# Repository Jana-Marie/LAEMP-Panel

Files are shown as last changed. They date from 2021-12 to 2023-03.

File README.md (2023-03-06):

# LAEMP-Panel

LAEMP-Panel is a Zigbee controllable (e.g. philips hue) RGBY + W spot, which can be soldered at home and is easy to assemble. The extra yellow channel gives a much wider dynamic. This is archived by alternating CW/WW/A (Cold-, Warm-White, Amber) and RGB LEDs. LAEMP-Panel can be mounted on mini-tripods and is powered via 5V USB Type-C. A ZigBee bridge (e.g. Philips Hue) is needed for control.

<table>
  <tbody>
    <tr>
      <td>
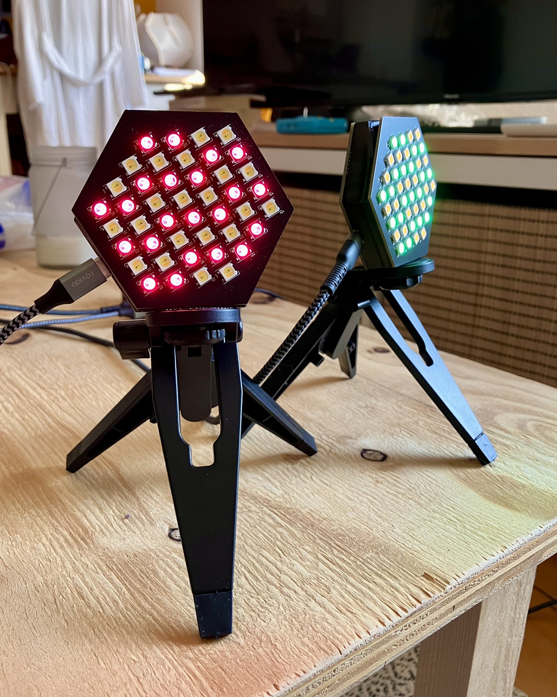
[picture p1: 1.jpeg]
        
      </td>
      <td>
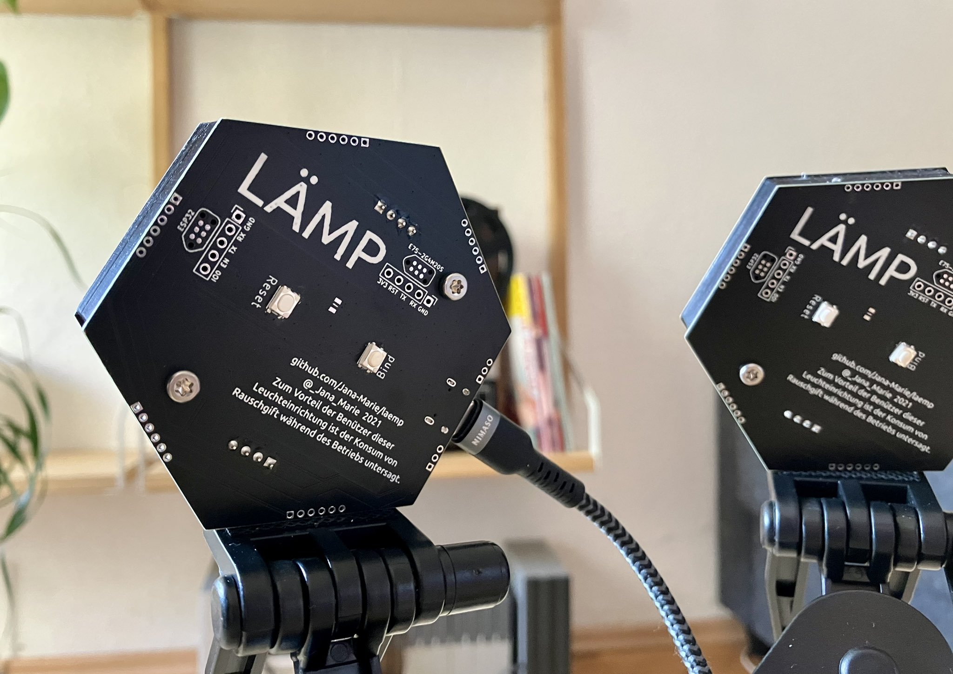
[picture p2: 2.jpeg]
        
      </td>
    </tr>
  </tbody>
</table>

### Sister project

LAEMP-Panel is a sister project to [LAEMP-Prism](https://github.com/Jana-Marie/LAEMP-Prism)

## Firmware

There are two firmwares to be flashed, one for the ESP32 and one for the E75-2G4M20S.

### ESP32

This is a simple Arduino project and can be flashed via Arduino (initially built on Arduino 1.8.19).

### E75

Please refer to the awesome works of [PeeVeeOne](https://peeveeone.com/zll-tldr/) to flash `Light_ColorLight_JN5168_RGB` onto the E75-2G4M20S module.

## Todo

 - [ ] Profile CRI
   - [ ] Increase CRI by selectively adding colors to WW/CW (i.e. green)
 - [ ] Update Baseboard to v2

## License

Copyright Jana Marie Hemsing 2023.
This source describes Open Hardware and is licensed under the CERN-
OHL-S v2.

You may redistribute and modify this source and make products using it
under the terms of the CERN-OHL-S v2
([LICENSE](/LICENSE)).

This source is distributed WITHOUT ANY EXPRESS OR IMPLIED
WARRANTY, INCLUDING OF MERCHANTABILITY, SATISFACTORY
QUALITY AND FITNESS FOR A PARTICULAR PURPOSE. Please see
the CERN-OHL-S v2 for applicable conditions.

Source location: https://github.com/Jana-Marie/LAEMP-Panel/
As per CERN-OHL-S v2 section 4, should You produce hardware based
on this source, You must where practicable maintain the Source Location
visible on the external case of LAEMP-Panel or other products you make using
this source

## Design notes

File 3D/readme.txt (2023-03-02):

You might need to change the height of the 3D printed part by a few mm depending on your printer. 14mm worked out well for me on an Anycubic Photon UV resin printer.

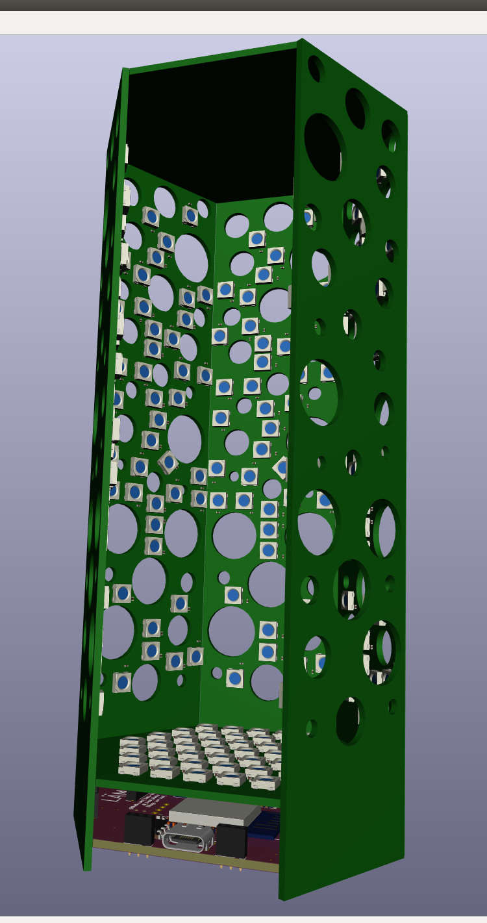
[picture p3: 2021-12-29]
design/img/full_open.png

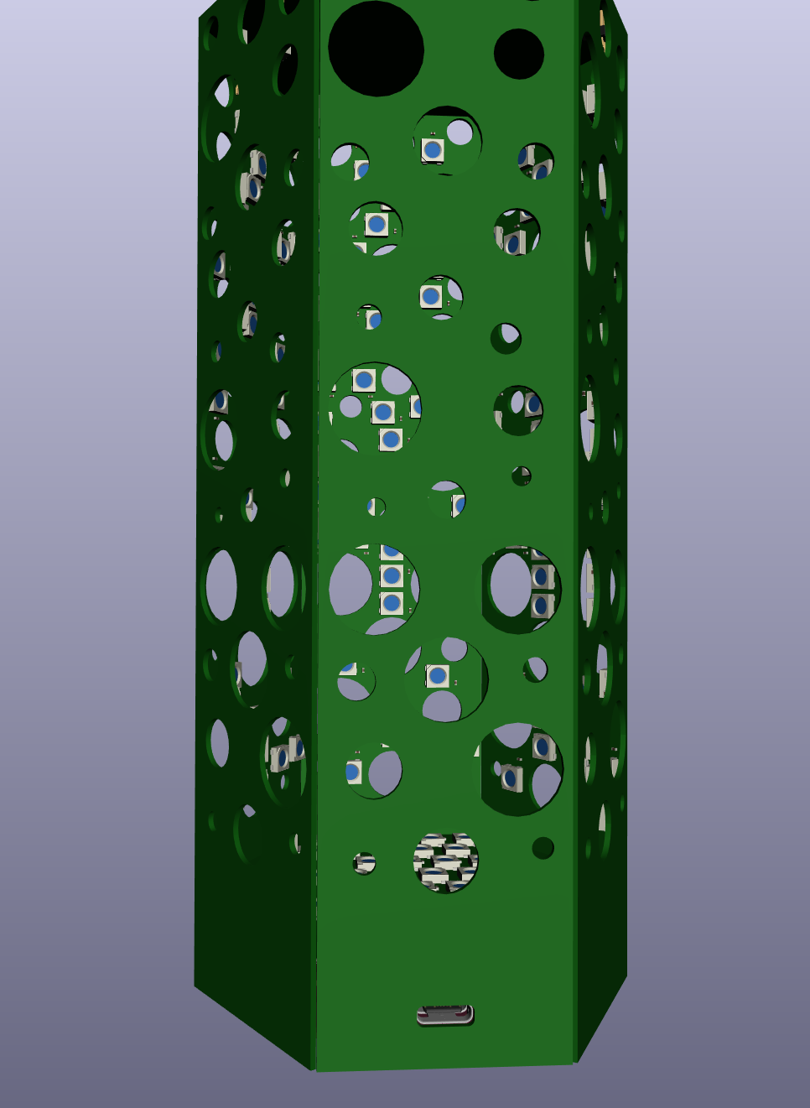
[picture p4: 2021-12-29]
design/img/usb.png

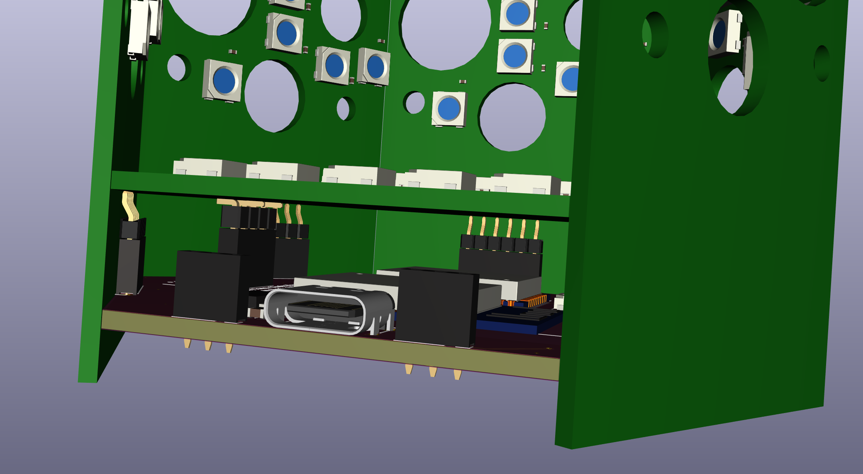
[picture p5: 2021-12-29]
design/img/mainboard.png

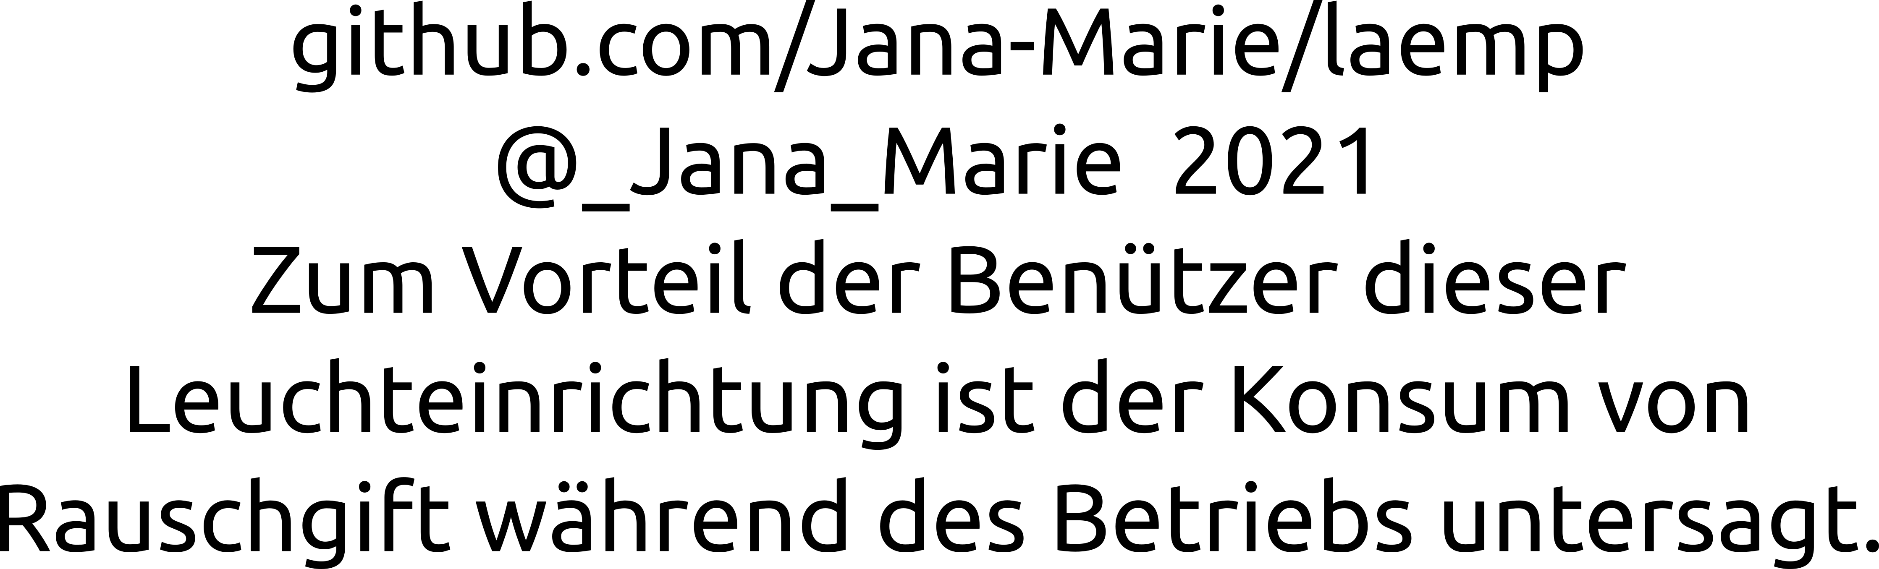
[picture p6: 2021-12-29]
design/bottom_text.png

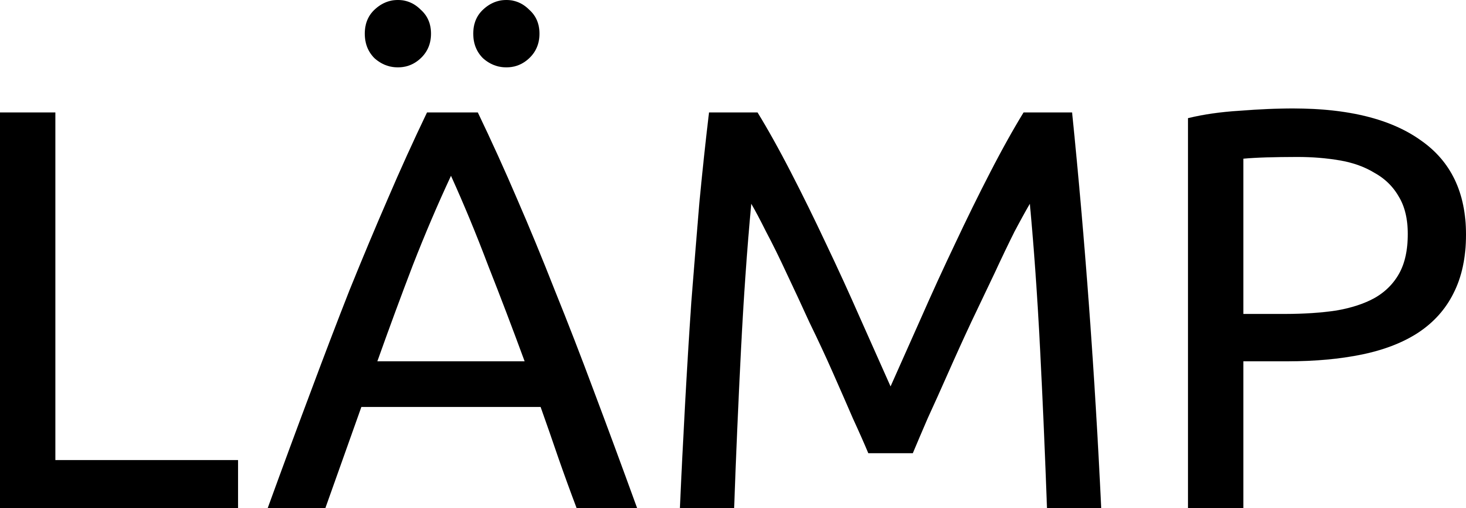
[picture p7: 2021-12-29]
design/laemp.png

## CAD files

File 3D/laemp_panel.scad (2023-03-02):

$fn=100;

color([0, 49/255, 83/255])laemp_panel_inner3D(14, false);

module laemp_panel_inner3D(h=10, thread=false){
    union(){
        // outer hexagon
        difference(){
            rotate([0,0,90])hexagon(40,h);
            translate([0,0,-0.5])rotate([0,0,90])hexagon(36,h+1);
            // usb cutout
            translate([-33,0,3.2/2-0.5])minkowski(){
                d=2;
                cube([5,9.5-d,3.2+1-d],center=true);
                rotate([0,90,0])cylinder(d=d,h=0.1);
            }
            // 1/4" thread
            if(thread==true){
                rotate([90,0,-30])translate([0,h/2,30])thread(6.35,5.35,1.27,6,10);
            } else {
                reduce=1.6;
                rotate([90,0,-30])translate([0,h/2,30])cylinder(d=6.35-reduce, h=6);
            }
        }
        // screwholes
        translate([-17,20,0])mounting_holes(2.5,h,2);
        translate([17,-20,0])mounting_holes(2.5,h,2);
        // bridges
        translate([-17,20,h/2]){
            rotate([0,0,90])translate([3+2,0,0])cube([6,2,h],center=true);
            rotate([0,0,170])translate([5+2,0,0])cube([10,2,h],center=true);
        }
        translate([17,-20,h/2]){
            rotate([0,0,-90])translate([3+2,0,0])cube([6,2,h],center=true);
            rotate([0,0,-10])translate([5+2,0,0])cube([10,2,h],center=true);
        }
    }
}

module thread(do=10,di=9,s=1.9,h=10,res=5){
    ssize=360/res;
    for(i=[1:res:360/s*h]){
        rotate([0,0,i])translate([(do-di)/2,0,s*i/360-0.01])cylinder(h=s/ssize+0.02,d=di);
    }
}

module mounting_holes(sDia=3,h=1,wall=2){
    difference(){
        cylinder(d=wall*2+sDia,h=h);
        translate([0,0,-0.5])cylinder(d=sDia,h=h+1);
    }
}

module hexagon(x = 10, h = 1){
    cylinder(d=x*2, h=h, $fn=6);
}

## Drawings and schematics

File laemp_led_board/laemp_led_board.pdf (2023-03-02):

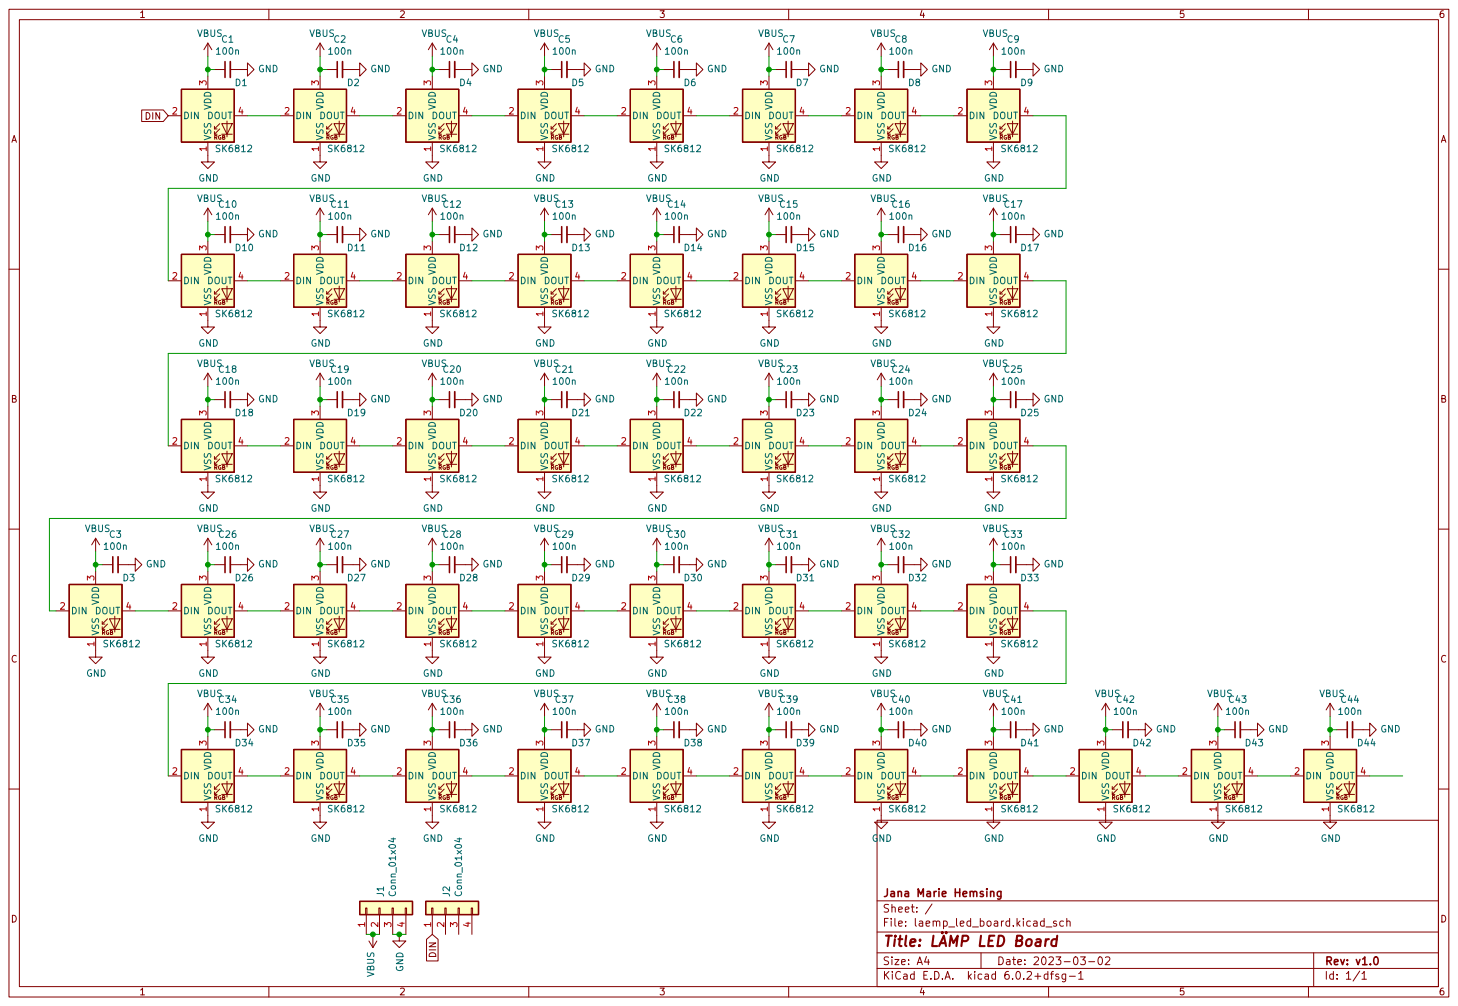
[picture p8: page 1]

3 DOUT 4D35 SK6812 GND GND GND GND VSS RGB 1 DIN 2 VDD

3 DOUT 4D6 SK6812 VBUS VSS RGB 1 DIN 2 VDD

3 DOUT 4D8 SK6812 GNDVSS RGB 1 DIN 2 VDD

3 DOUT 4D11 SK6812 VSS RGB 1 DIN 2 VDD

3 DOUT 4D27 SK6812 VSS RGB 1 DIN 2 VDD

3 DOUT 4D19 SK6812 GND VSS RGB 1 DIN 2 VDD

3 DOUT 4D14 SK6812 GND VSS RGB 1 DIN 2 VDD

3 DOUT 4D15 SK6812 VSS RGB 1 DIN 2 VDD

3 DOUT 4D13 SK6812 VSS RGB 1 DIN 2 VDD

3 DOUT 4D32 SK6812 VBUS GND VSS RGB 1 DIN 2 VDD

3 DOUT 4D25 SK6812 VBUS GND GND

3 DOUT 4D28 SK6812 VSS RGB 1 DIN 2 VDD

File: laemp_led_board.kicad_sch Sheet: / Jana Marie Hemsing

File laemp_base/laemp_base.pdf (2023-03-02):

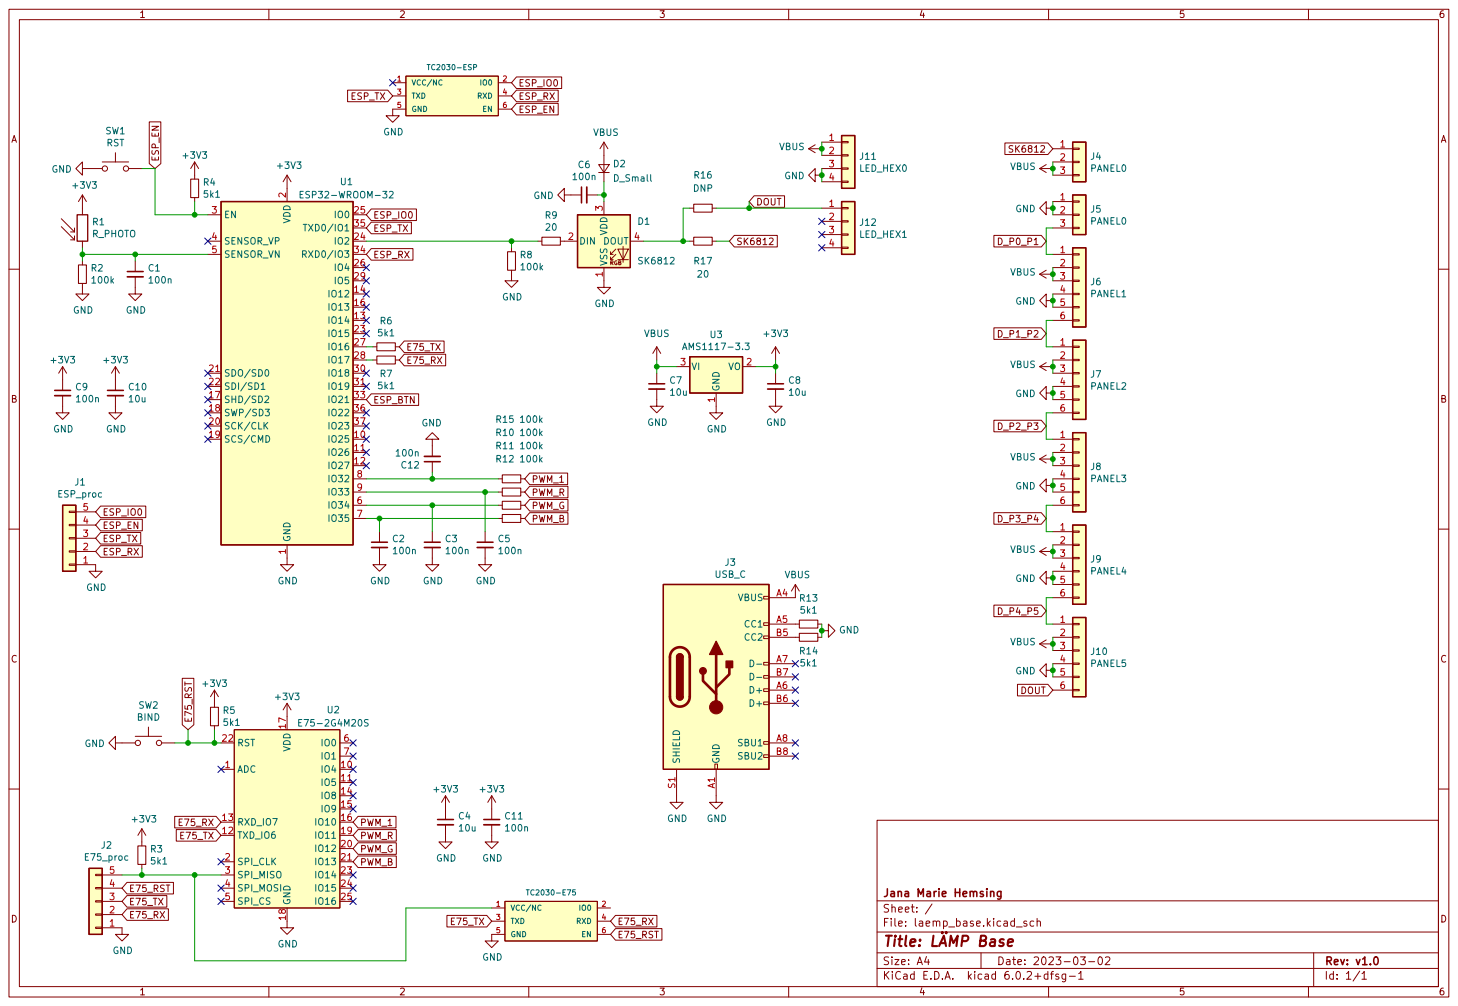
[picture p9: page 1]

File: laemp_base.kicad_sch Sheet: / Jana Marie Hemsing

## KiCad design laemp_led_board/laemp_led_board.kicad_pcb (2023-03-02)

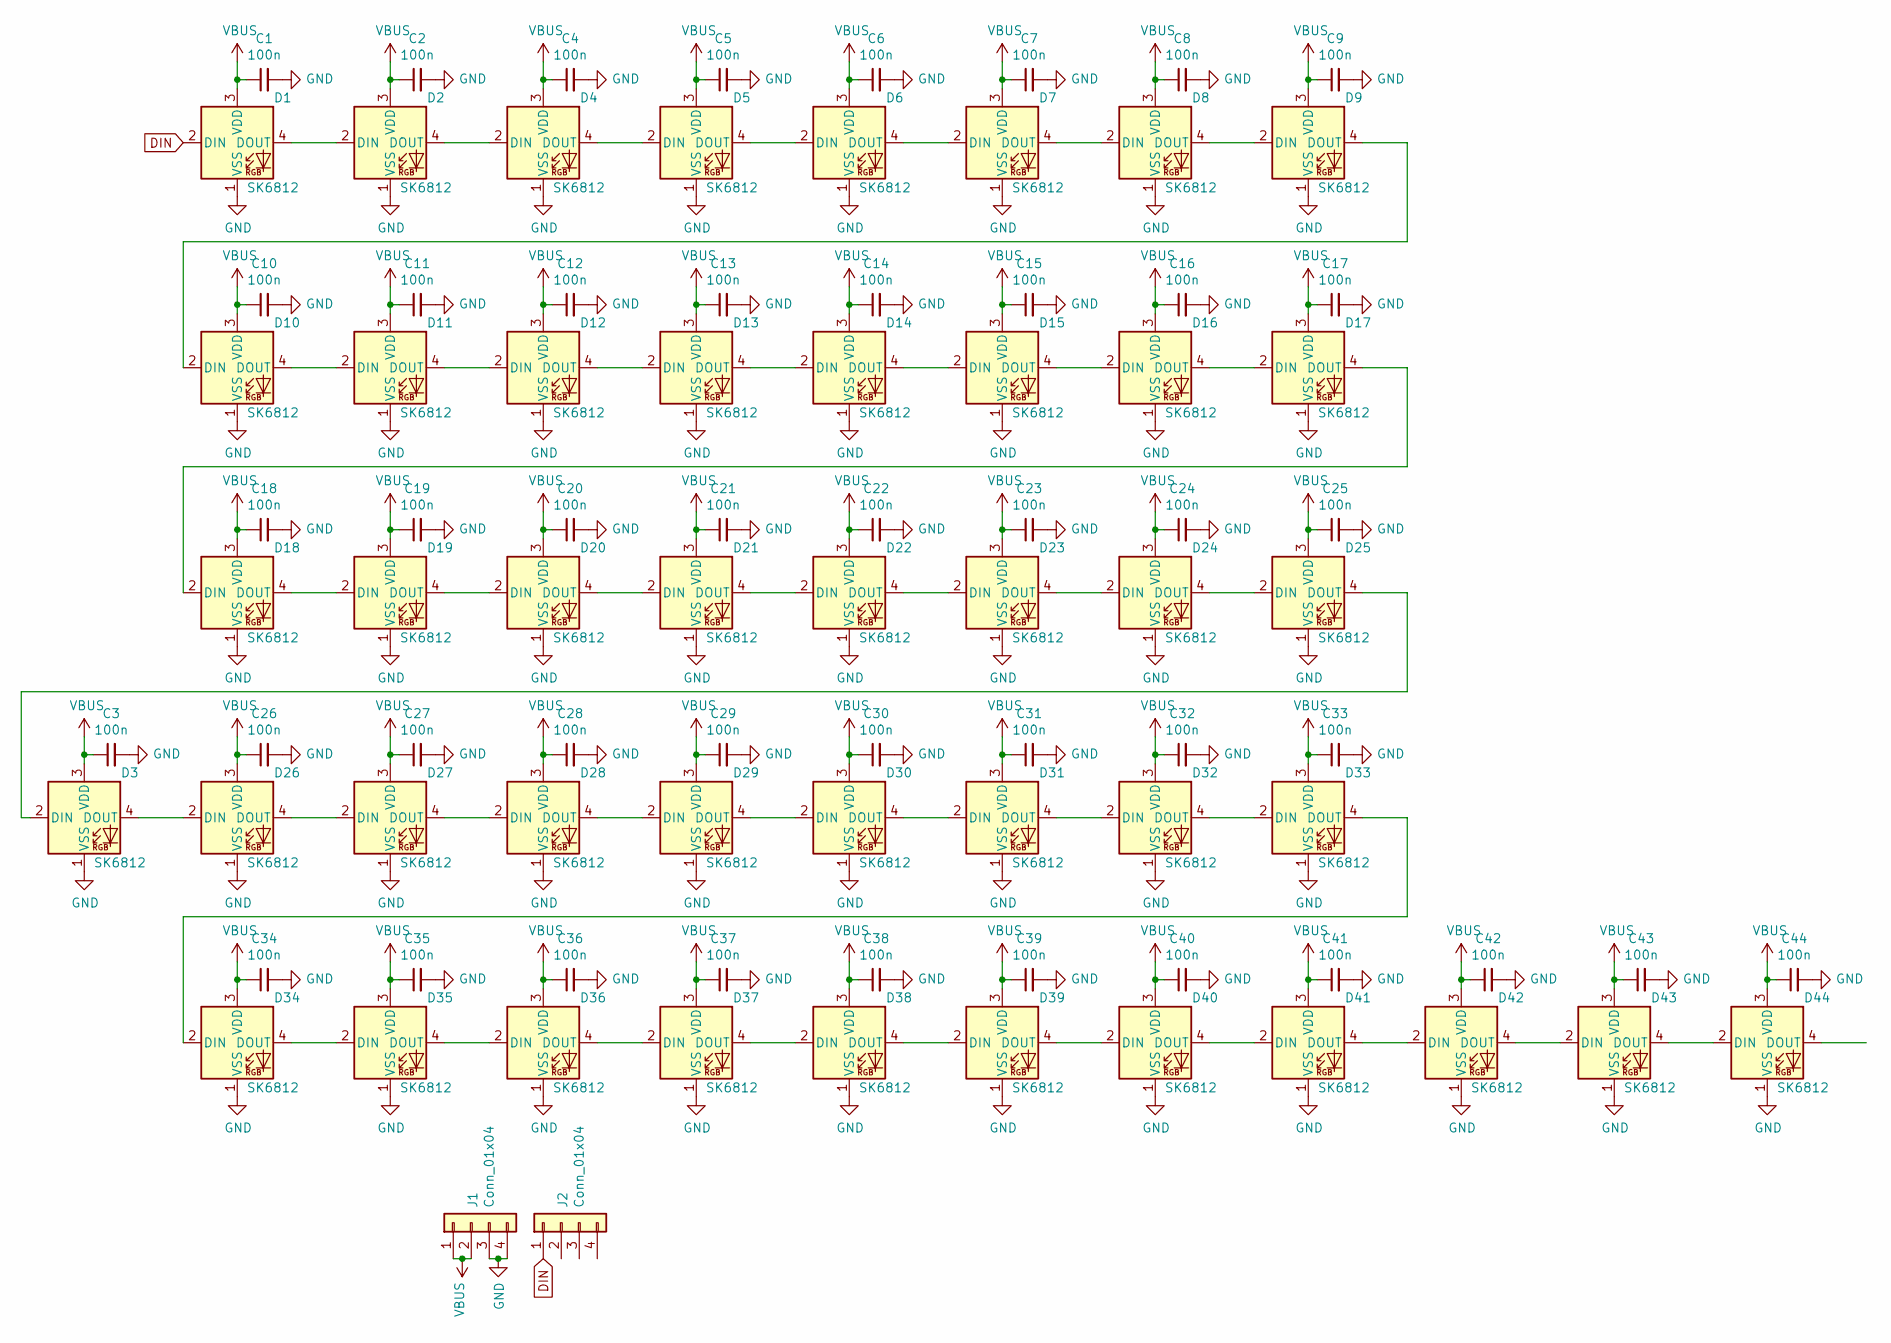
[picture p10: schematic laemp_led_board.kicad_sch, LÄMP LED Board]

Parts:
C1, C2, C3, C4, C5, C6, C7, C8, C9, C10, C11, C12, C13, C14, C15, C16, C17, C18, C19, C20, C21, C22, C23, C24, C25, C26, C27, C28, C29, C30, C31, C32, C33, C34, C35, C36, C37, C38, C39, C40, C41, C42, C43, C44: 100n; C_0402
D1, D2, D3, D4, D5, D6, D7, D8, D9, D10, D11, D12, D13, D14, D15, D16, D17, D18, D19, D20, D21, D22, D23, D24, D25, D26, D27, D28, D29, D30, D31, D32, D33, D34, D35, D36, D37, D38, D39, D40, D41, D42, D43, D44: SK6812; LED_SK6812_PLCC4_5.0x5.0mm_P3.2mm
J1, J2: Conn_01x04; PinHeader_1x04_P2.54mm_Vertical_SMD_Pin1Left

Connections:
DIN: D1.2 (DIN), J2.1
GND: C1.2, C2.2, C3.2, C4.2, C5.2, C6.2, C7.2, C8.2, C9.2, C10.2, C11.2, C12.2, C13.2, C14.2, C15.2, C16.2, C17.2, C18.2, C19.2, C20.2, C21.2, C22.2, C23.2, C24.2, C25.2, C26.2, C27.2, C28.2, C29.2, C30.2, C31.2, C32.2, C33.2, C34.2, C35.2, C36.2, C37.2, C38.2, C39.2, C40.2, C41.2, C42.2, C43.2, C44.2, D1.1 (VSS), D2.1 (VSS), D3.1 (VSS), D4.1 (VSS), D5.1 (VSS), D6.1 (VSS), D7.1 (VSS), D8.1 (VSS), D9.1 (VSS), D10.1 (VSS), D11.1 (VSS), D12.1 (VSS), D13.1 (VSS), D14.1 (VSS), D15.1 (VSS), D16.1 (VSS), D17.1 (VSS), D18.1 (VSS), D19.1 (VSS), D20.1 (VSS), D21.1 (VSS), D22.1 (VSS), D23.1 (VSS), D24.1 (VSS), D25.1 (VSS), D26.1 (VSS), D27.1 (VSS), D28.1 (VSS), D29.1 (VSS), D30.1 (VSS), D31.1 (VSS), D32.1 (VSS), D33.1 (VSS), D34.1 (VSS), D35.1 (VSS), D36.1 (VSS), D37.1 (VSS), D38.1 (VSS), D39.1 (VSS), D40.1 (VSS), D41.1 (VSS), D42.1 (VSS), D43.1 (VSS), D44.1 (VSS), J1.3, J1.4
unnamed: D1.4 (DOUT), D2.2 (DIN)
unnamed: D2.4 (DOUT), D4.2 (DIN)
unnamed: D4.4 (DOUT), D5.2 (DIN)
unnamed: D5.4 (DOUT), D6.2 (DIN)
unnamed: D6.4 (DOUT), D7.2 (DIN)
unnamed: D7.4 (DOUT), D8.2 (DIN)
unnamed: D8.4 (DOUT), D9.2 (DIN)
unnamed: D9.4 (DOUT), D10.2 (DIN)
unnamed: D10.4 (DOUT), D11.2 (DIN)
unnamed: D11.4 (DOUT), D12.2 (DIN)
unnamed: D12.4 (DOUT), D13.2 (DIN)
unnamed: D13.4 (DOUT), D14.2 (DIN)
unnamed: D14.4 (DOUT), D15.2 (DIN)
unnamed: D15.4 (DOUT), D16.2 (DIN)
unnamed: D16.4 (DOUT), D17.2 (DIN)
unnamed: D17.4 (DOUT), D18.2 (DIN)
unnamed: D18.4 (DOUT), D19.2 (DIN)
unnamed: D19.4 (DOUT), D20.2 (DIN)
unnamed: D20.4 (DOUT), D21.2 (DIN)
unnamed: D21.4 (DOUT), D22.2 (DIN)
unnamed: D22.4 (DOUT), D23.2 (DIN)
unnamed: D23.4 (DOUT), D24.2 (DIN)
unnamed: D24.4 (DOUT), D25.2 (DIN)
unnamed: D3.2 (DIN), D25.4 (DOUT)
unnamed: D3.4 (DOUT), D26.2 (DIN)
unnamed: D26.4 (DOUT), D27.2 (DIN)
unnamed: D27.4 (DOUT), D28.2 (DIN)
unnamed: D28.4 (DOUT), D29.2 (DIN)
unnamed: D29.4 (DOUT), D30.2 (DIN)
unnamed: D30.4 (DOUT), D31.2 (DIN)
unnamed: D31.4 (DOUT), D32.2 (DIN)
unnamed: D32.4 (DOUT), D33.2 (DIN)
unnamed: D33.4 (DOUT), D34.2 (DIN)
unnamed: D34.4 (DOUT), D35.2 (DIN)
unnamed: D35.4 (DOUT), D36.2 (DIN)
unnamed: D36.4 (DOUT), D37.2 (DIN)
unnamed: D37.4 (DOUT), D38.2 (DIN)
unnamed: D38.4 (DOUT), D39.2 (DIN)
unnamed: D39.4 (DOUT), D40.2 (DIN)
unnamed: D40.4 (DOUT), D41.2 (DIN)
unnamed: D41.4 (DOUT), D42.2 (DIN)
unnamed: D42.4 (DOUT), D43.2 (DIN)
unnamed: D43.4 (DOUT), D44.2 (DIN)
VBUS: C1.1, C2.1, C3.1, C4.1, C5.1, C6.1, C7.1, C8.1, C9.1, C10.1, C11.1, C12.1, C13.1, C14.1, C15.1, C16.1, C17.1, C18.1, C19.1, C20.1, C21.1, C22.1, C23.1, C24.1, C25.1, C26.1, C27.1, C28.1, C29.1, C30.1, C31.1, C32.1, C33.1, C34.1, C35.1, C36.1, C37.1, C38.1, C39.1, C40.1, C41.1, C42.1, C43.1, C44.1, D1.3 (VDD), D2.3 (VDD), D3.3 (VDD), D4.3 (VDD), D5.3 (VDD), D6.3 (VDD), D7.3 (VDD), D8.3 (VDD), D9.3 (VDD), D10.3 (VDD), D11.3 (VDD), D12.3 (VDD), D13.3 (VDD), D14.3 (VDD), D15.3 (VDD), D16.3 (VDD), D17.3 (VDD), D18.3 (VDD), D19.3 (VDD), D20.3 (VDD), D21.3 (VDD), D22.3 (VDD), D23.3 (VDD), D24.3 (VDD), D25.3 (VDD), D26.3 (VDD), D27.3 (VDD), D28.3 (VDD), D29.3 (VDD), D30.3 (VDD), D31.3 (VDD), D32.3 (VDD), D33.3 (VDD), D34.3 (VDD), D35.3 (VDD), D36.3 (VDD), D37.3 (VDD), D38.3 (VDD), D39.3 (VDD), D40.3 (VDD), D41.3 (VDD), D42.3 (VDD), D43.3 (VDD), D44.3 (VDD), J1.1, J1.2

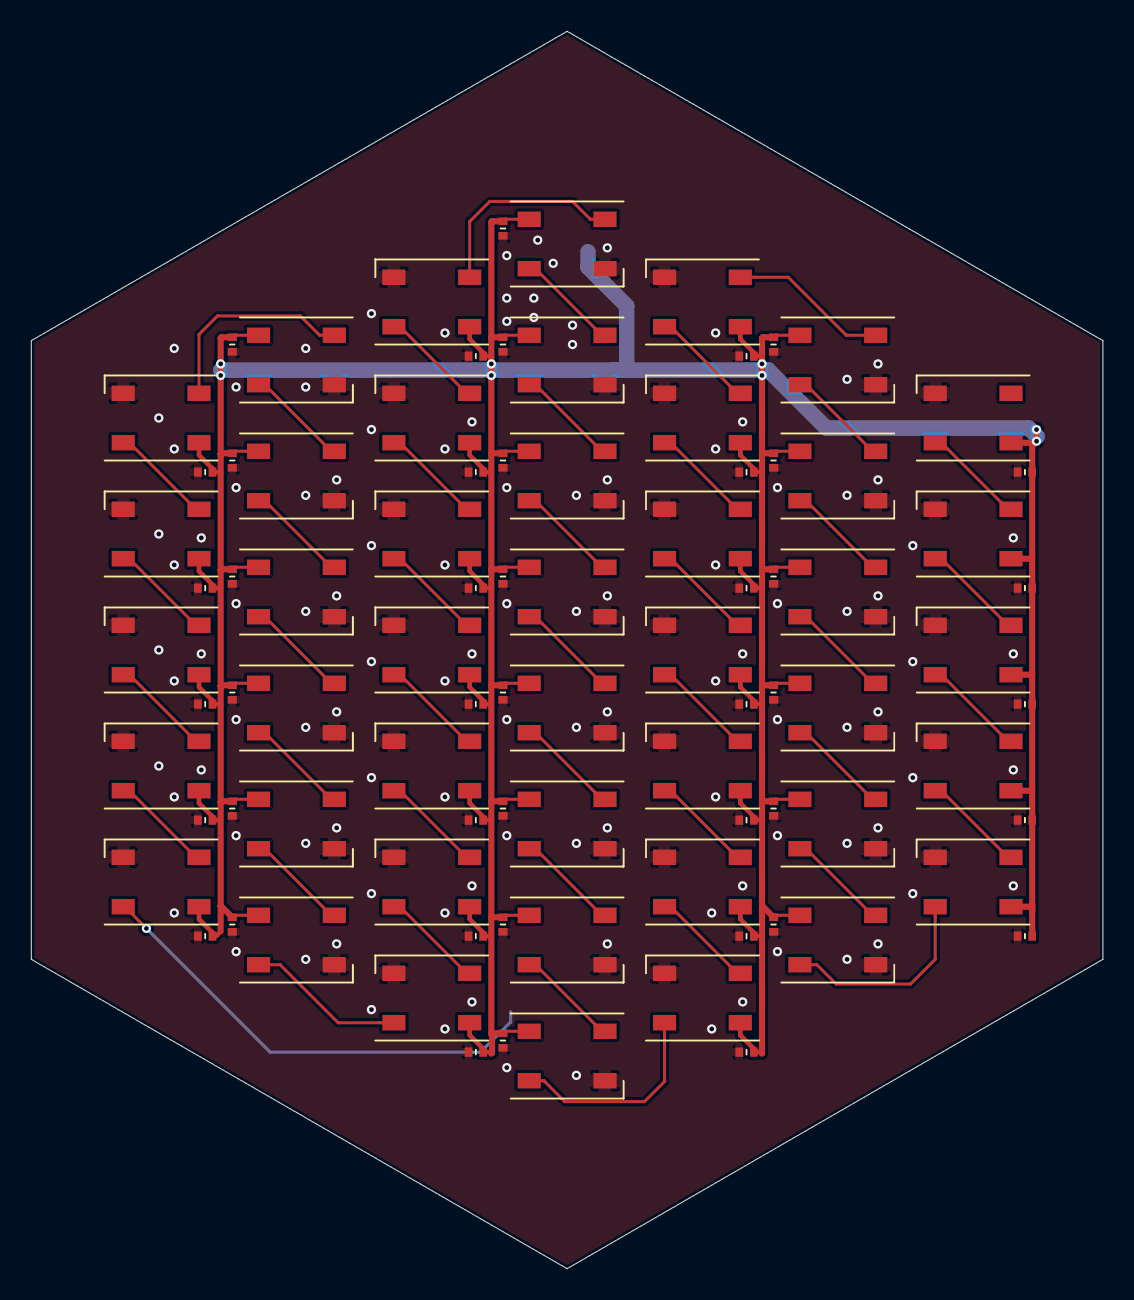
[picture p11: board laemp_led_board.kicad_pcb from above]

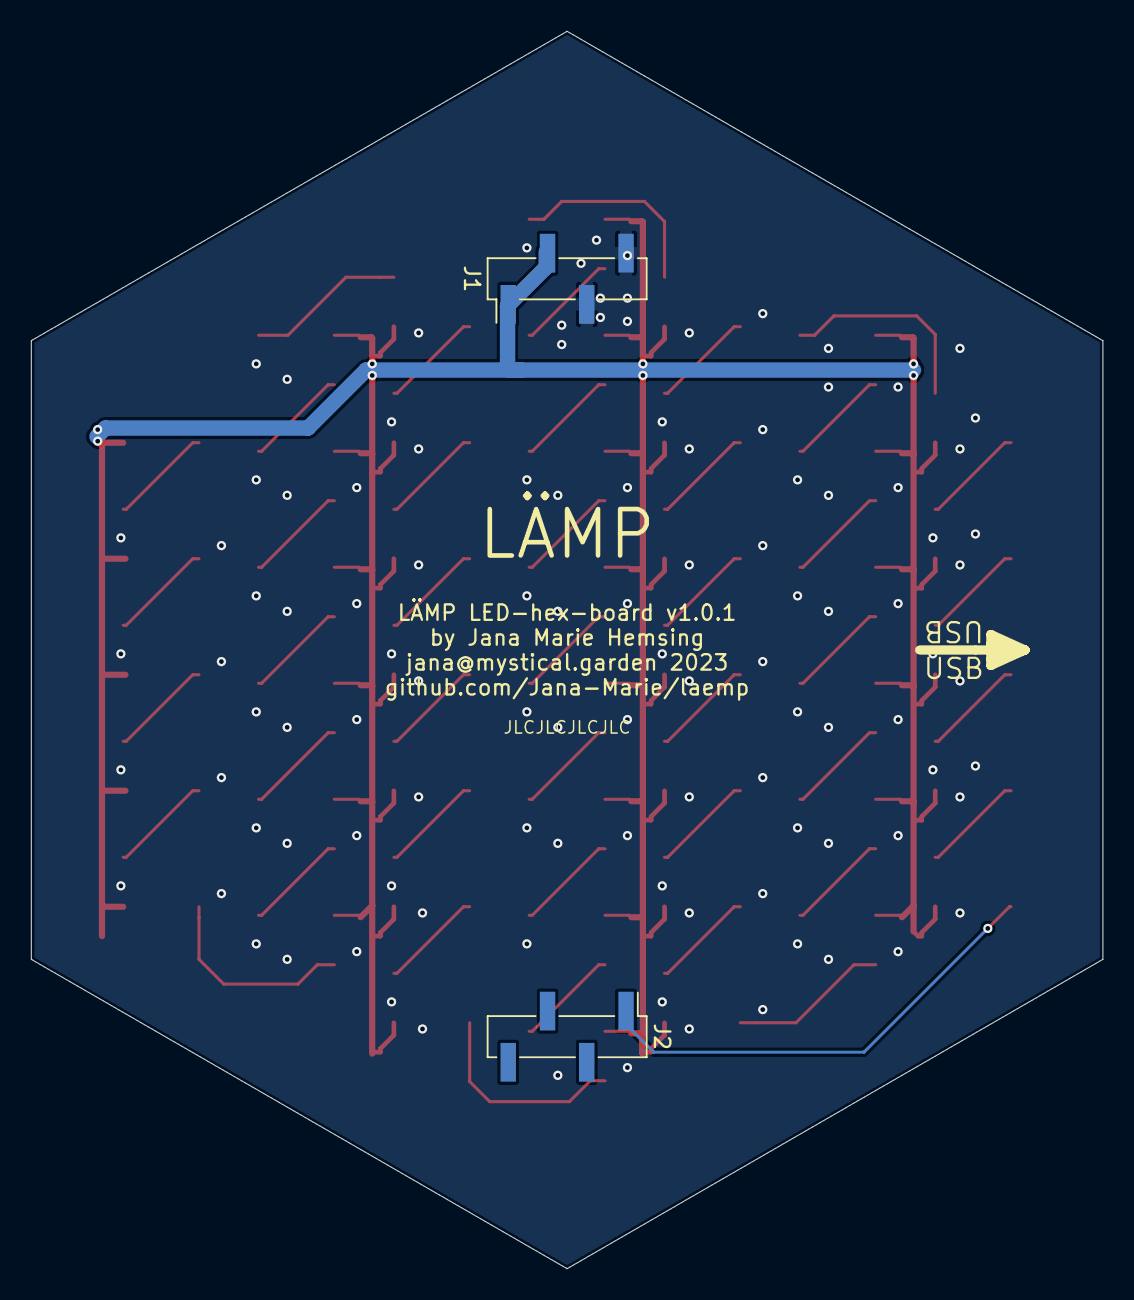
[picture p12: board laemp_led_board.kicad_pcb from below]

Board: 2 copper layers, 69.3 x 80.0 mm, 90 parts (2 on the bottom side), 46 nets.

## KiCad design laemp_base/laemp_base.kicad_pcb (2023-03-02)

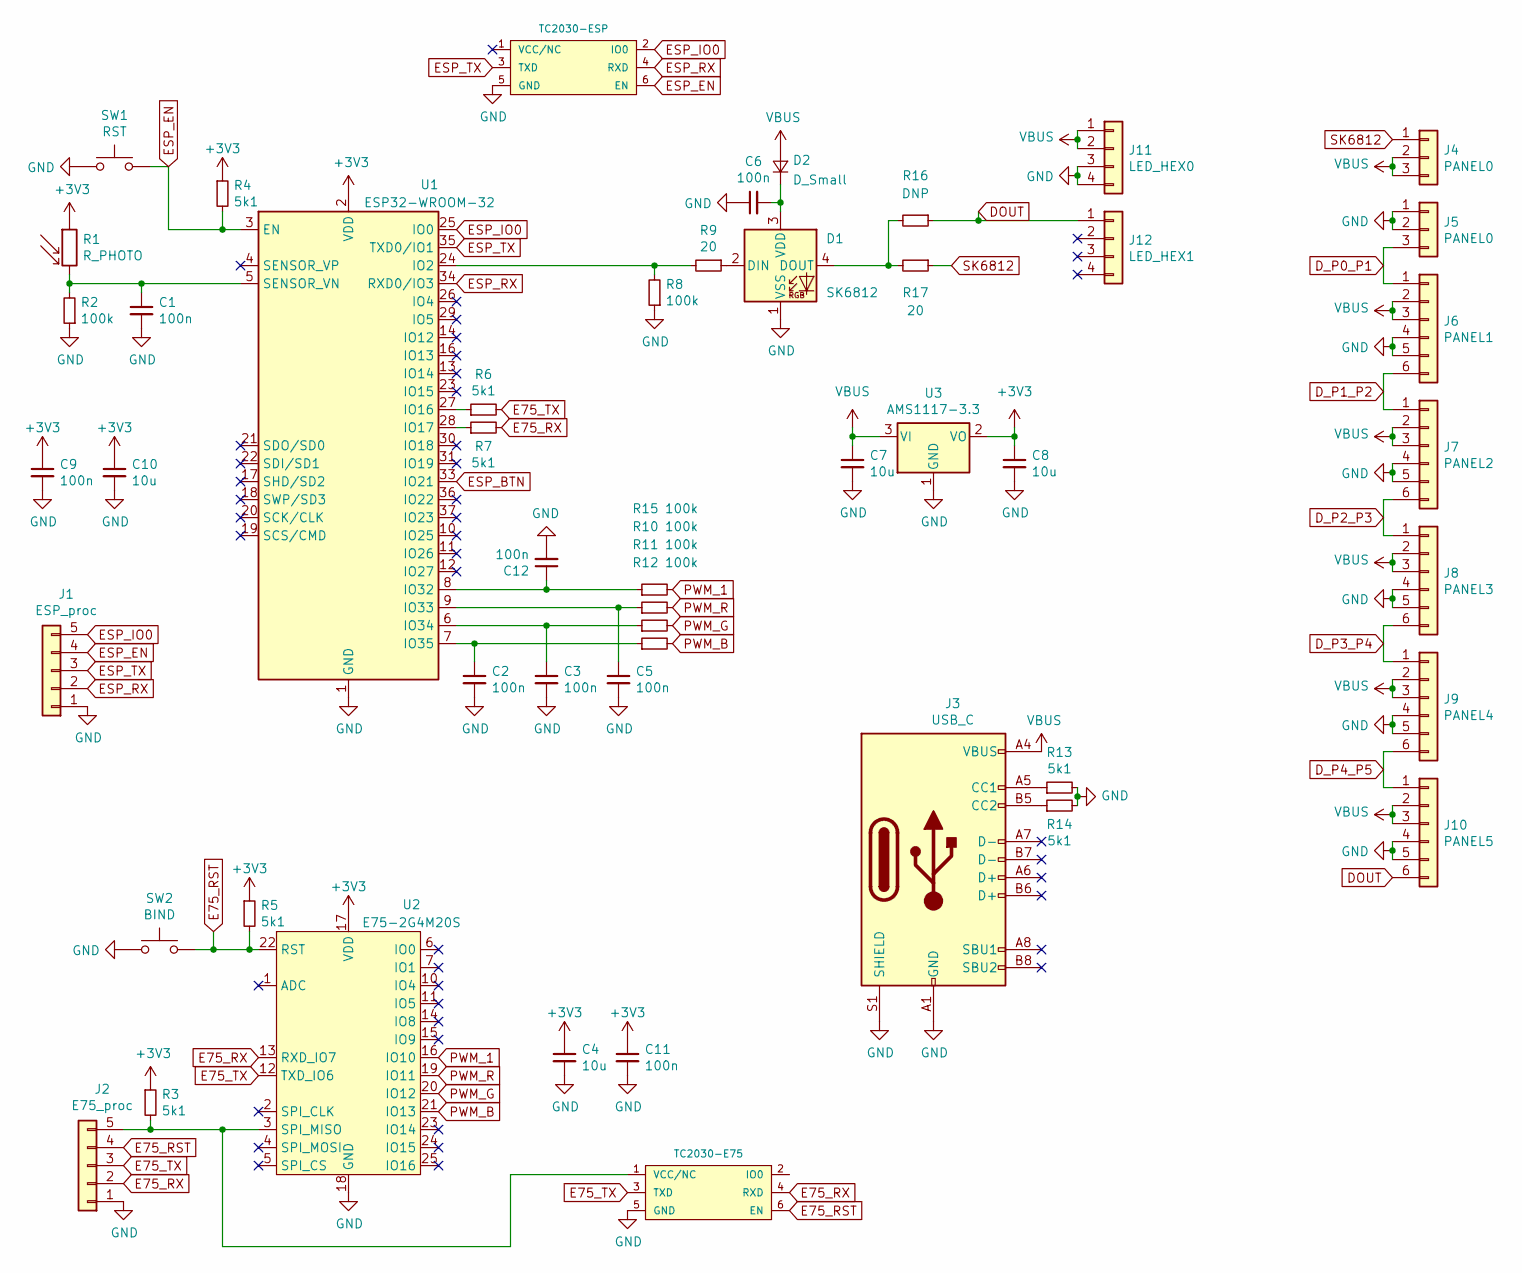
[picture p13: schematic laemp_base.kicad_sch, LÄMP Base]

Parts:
C1, C2, C3, C5, C6, C9, C11, C12: 100n; C_0402
C4, C7, C8, C10: 10u; C_0603
D1: SK6812; LED_SK6812_PLCC4_5.0x5.0mm_P3.2mm
D2: D_Small; D_SOD-123F
J1: ESP_proc; PinHeader_1x05_P2.54mm_Vertical
J2: E75_proc; PinHeader_1x05_P2.54mm_Vertical
J3: USB_C; USB-C 16Pin
J4, J5: PANEL0; PinSocket_1x03_P2.00mm_Vertical
J6: PANEL1; PinSocket_1x06_P2.00mm_Vertical_center
J7: PANEL2; PinSocket_1x06_P2.00mm_Vertical_center
J8: PANEL3; PinSocket_1x06_P2.00mm_Vertical_center
J9: PANEL4; PinSocket_1x06_P2.00mm_Vertical_center
J10: PANEL5; PinSocket_1x06_P2.00mm_Vertical_center
J11: LED_HEX0; PinSocket_1x04_P2.54mm_Vertical_center
J12: LED_HEX1; PinSocket_1x04_P2.54mm_Vertical_center
P1: TC2030-ESP; TC2030
P2: TC2030-E75; TC2030
R1: R_PHOTO; R_0805
R2, R8, R10, R11, R12, R15: 100k; R_0402
R3, R4, R5, R6, R7, R13, R14: 5k1; R_0402
R9, R17: 20; R_0402
R16: DNP; R_0402
SW1: RST; SW_SPST_PTS810
SW2: BIND; SW_SPST_PTS810
U1: ESP32-WROOM-32
U2: E75-2G4M20S; E75-2G4M10S
U3: AMS1117-3.3; SOT-223-3_TabPin2

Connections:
+3V3: C4.1, C8.1, C9.1, C10.1, C11.1, R1.1, R3.1, R4.1, R5.1, U1.2 (VDD), U2.17 (VDD), U3.2 (VO)
DOUT: J10.6, J12.1, R16.1
D_P0_P1: J5.3, J6.1
D_P1_P2: J6.6, J7.1
D_P2_P3: J7.6, J8.1
D_P3_P4: J8.6, J9.1
D_P4_P5: J9.6, J10.1
E75_RST: J2.4, P2.6 (EN), R5.2, SW2.2, U2.22 (RST)
E75_RX: J2.2, P2.4 (RXD), R7.2, U2.13 (RXD_IO7)
E75_TX: J2.3, P2.3 (TXD), R6.2, U2.12 (TXD_IO6)
ESP_BTN: U1.33 (IO21)
ESP_EN: J1.4, P1.6 (EN), R4.2, SW1.2, U1.3 (EN)
ESP_IO0: J1.5, P1.2 (IO0), U1.25 (IO0)
ESP_RX: J1.2, P1.4 (RXD), U1.34 (RXD0/IO3)
ESP_TX: J1.3, P1.3 (TXD), U1.35 (TXD0/IO1)
GND: C1.2, C2.2, C3.2, C4.2, C5.2, C6.1, C7.2, C8.2, C9.2, C10.2, C11.2, C12.2, D1.1 (VSS), J1.1, J2.1, J3.A1 (GND), J3.A12 (GND), J3.B1 (GND), J3.B12 (GND), J3.S1 (SHIELD), J5.1, J5.2, J6.4, J6.5, J7.4, J7.5, J8.4, J8.5, J9.4, J9.5, J10.4, J10.5, J11.3, J11.4, P1.5 (GND), P2.5 (GND), R2.1, R8.1, R13.2, R14.2, SW1.1, SW2.1, U1.1 (GND), U1.15 (GND), U1.38 (GND), U1.39 (GND), U2.18 (GND), U3.1 (GND)
unnamed: C1.1, R1.2, R2.2, U1.5 (SENSOR_VN)
unnamed: C2.1, R12.1, U1.7 (IO35)
unnamed: C3.1, R11.1, U1.6 (IO34)
unnamed: C5.1, R10.1, U1.9 (IO33)
unnamed: C6.2, D1.3 (VDD), D2.1 (K)
unnamed: C12.1, R15.1, U1.8 (IO32)
unnamed: D1.2 (DIN), R9.1
unnamed: D1.4 (DOUT), R16.2, R17.2
unnamed: J2.5, P2.1 (VCC/NC), R3.2, U2.3 (SPI_MISO)
unnamed: J3.A5 (CC1), R13.1
unnamed: J3.B5 (CC2), R14.1
unnamed: R6.1, U1.27 (IO16)
unnamed: R7.1, U1.28 (IO17)
unnamed: R8.2, R9.2, U1.24 (IO2)
PWM_1: R15.2, U2.16 (IO10)
PWM_B: R12.2, U2.21 (IO13)
PWM_G: R11.2, U2.20 (IO12)
PWM_R: R10.2, U2.19 (IO11)
SK6812: J4.1, R17.1
VBUS: C7.1, D2.2 (A), J3.A4 (VBUS), J3.A9 (VBUS), J3.B4 (VBUS), J3.B9 (VBUS), J4.2, J4.3, J6.2, J6.3, J7.2, J7.3, J8.2, J8.3, J9.2, J9.3, J10.2, J10.3, J11.1, J11.2, U3.3 (VI)

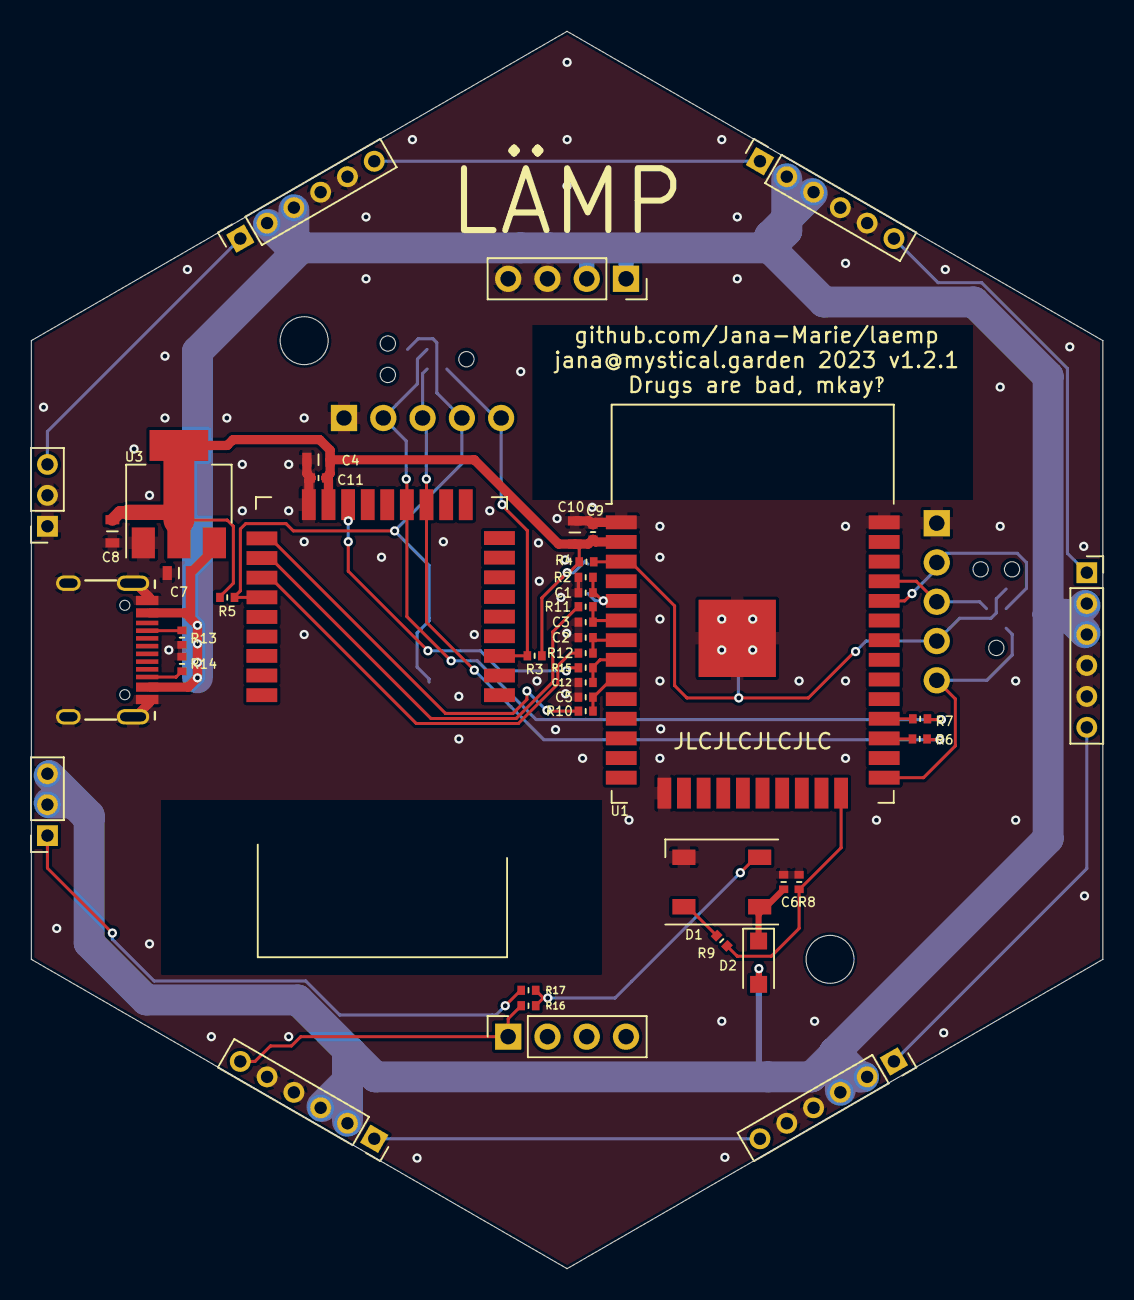
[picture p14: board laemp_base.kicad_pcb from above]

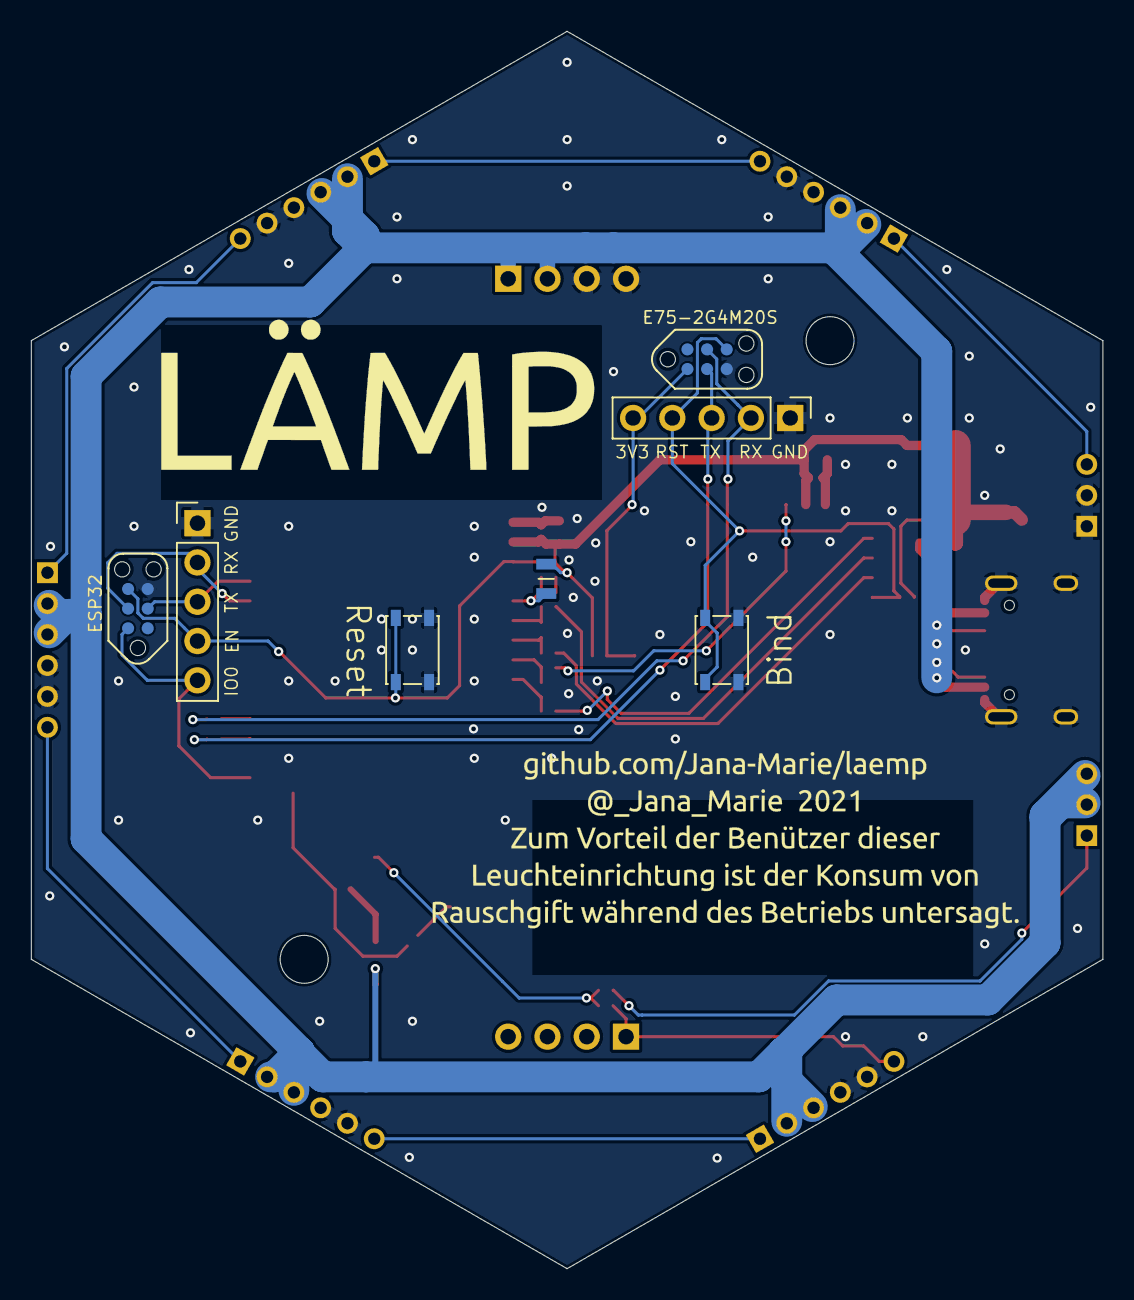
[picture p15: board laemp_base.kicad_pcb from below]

Board: 2 copper layers, 69.3 x 80.0 mm, 50 parts (7 on the bottom side), 35 nets.

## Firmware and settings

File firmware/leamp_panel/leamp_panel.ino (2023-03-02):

#include <Adafruit_NeoPixel.h>

#define minf(a,b) (((a)<(b))?(a):(b))
#define maxf(a,b) (((a)>(b))?(a):(b))

#define PIN 2
Adafruit_NeoPixel strip = Adafruit_NeoPixel(45, PIN, NEO_GRB + NEO_KHZ800);

#define R_IN 33
#define G_IN 34
#define B_IN 35

int16_t adc_color[3] = {0, 0, 0};
uint8_t hue_color[3] = {0, 0, 0};

uint16_t wakeup = false;

byte neopix_gamma[] = {
  0,  0,  0,  0,  0,  0,  0,  0,  0,  0,  0,  0,  0,  0,  0,  0,
  0,  0,  0,  0,  0,  0,  0,  0,  0,  0,  0,  0,  1,  1,  1,  1,
  1,  1,  1,  1,  1,  1,  1,  1,  1,  2,  2,  2,  2,  2,  2,  2,
  2,  3,  3,  3,  3,  3,  3,  3,  4,  4,  4,  4,  4,  5,  5,  5,
  5,  6,  6,  6,  6,  7,  7,  7,  7,  8,  8,  8,  9,  9,  9, 10,
  10, 10, 11, 11, 11, 12, 12, 13, 13, 13, 14, 14, 15, 15, 16, 16,
  17, 17, 18, 18, 19, 19, 20, 20, 21, 21, 22, 22, 23, 24, 24, 25,
  25, 26, 27, 27, 28, 29, 29, 30, 31, 32, 32, 33, 34, 35, 35, 36,
  37, 38, 39, 39, 40, 41, 42, 43, 44, 45, 46, 47, 48, 49, 50, 50,
  51, 52, 54, 55, 56, 57, 58, 59, 60, 61, 62, 63, 64, 66, 67, 68,
  69, 70, 72, 73, 74, 75, 77, 78, 79, 81, 82, 83, 85, 86, 87, 89,
  90, 92, 93, 95, 96, 98, 99, 101, 102, 104, 105, 107, 109, 110, 112, 114,
  115, 117, 119, 120, 122, 124, 126, 127, 129, 131, 133, 135, 137, 138, 140, 142,
  144, 146, 148, 150, 152, 154, 156, 158, 160, 162, 164, 167, 169, 171, 173, 175,
  177, 180, 182, 184, 186, 189, 191, 193, 196, 198, 200, 203, 205, 208, 210, 213,
  215, 218, 220, 223, 225, 228, 231, 233, 236, 239, 241, 244, 247, 249, 252, 255
};

struct rgbywwcw {
  uint8_t r;
  uint8_t g;
  uint8_t b;
  uint8_t y;
  uint8_t ww;
  uint8_t cw;
};

rgbywwcw led;
rgbywwcw led_f;

typedef struct {
  double h;       // angle in degrees
  double s;       // a fraction between 0 and 1
  double v;       // a fraction between 0 and 1
} hsv;

void setup() {
  Serial.begin(115200);
  strip.begin();
  strip.show();
  strip.setBrightness(255);
  delay(500);
}

uint16_t i;

void loop() {
  adc_color[0] = (analogRead(R_IN));
  adc_color[1] = (analogRead(G_IN));
  adc_color[2] = (analogRead(B_IN));

  Serial.print(adc_color[0]);
  Serial.print("\t");
  Serial.print(adc_color[1]);
  Serial.print("\t");
  Serial.println(adc_color[2]);
  
  if (adc_color[0] >= 4094 && adc_color[1] >= 4094 && adc_color[2] >= 4094) {
    hue_color[0] = 0;
    hue_color[1] = 0;
    hue_color[2] = 0;
    wakeup = 50;
    setColor(rgbywwcw{0, 0, 0, 0, 0, 0});
    delay(50);
  } else {
    hue_color[0] = map(adc_color[0], 0, 4095, wakeup, 0);
    hue_color[1] = map(adc_color[1], 0, 4095, wakeup, 0);
    hue_color[2] = map(adc_color[2], 0, 4095, wakeup, 0);
    wakeup++;
    if (wakeup > 255) {
      wakeup = 255;
    }
    setColor(_f(rgb_to_rgbw(hsv_to_rgby_naive(rgb2hsv(hue_color[0] / 255.0, hue_color[1] / 255.0, hue_color[2] / 255.0)))));
    delay(1);
  }
  
  //i++;
  //i = i %360;
  //setColor(_f(rgb_to_rgbw(hsv_to_rgby_naive(test(i)))));
  //Serial.println("Meow");
  delay(10);
}

hsv test(uint16_t i){
  hsv _hsv;
  _hsv.s = 1.0;
  _hsv.v =1.0;
  _hsv.h = i;
  return _hsv;
}

void setColor(rgbywwcw in) {
  uint32_t col = 0;
  uint32_t white = 0;

  col = strip.Color(neopix_gamma[in.r], neopix_gamma[in.g], neopix_gamma[in.b]);
  white =  strip.Color(neopix_gamma[in.y], neopix_gamma[in.cw], neopix_gamma[in.ww]);
  
  strip.setPixelColor(0, (0,0,0));
  
  for (uint16_t i = 1; i < strip.numPixels(); i += 2) {
    //if (i == 18 || i == 40) strip.setPixelColor(i + 1, col);
    strip.setPixelColor(i, col);
  }
  for (uint16_t i = 2; i < strip.numPixels(); i += 2) {
    //if (i == 19 || i == 41) strip.setPixelColor(i - 1, white);
    strip.setPixelColor(i, white);
  }
  strip.show();
}

#define FILT_COEF 0.1
rgbywwcw _f(rgbywwcw in) {
  led_f.r = (led_f.r * (1.0 - FILT_COEF)) + (in.r * FILT_COEF);
  led_f.g = (led_f.g * (1.0 - FILT_COEF)) + (in.g * FILT_COEF);
  led_f.b = (led_f.b * (1.0 - FILT_COEF)) + (in.b * FILT_COEF);
  led_f.y = (led_f.y * (1.0 - FILT_COEF)) + (in.y * FILT_COEF);
  led_f.ww = (led_f.ww * (1.0 - FILT_COEF)) + (in.ww * FILT_COEF);
  led_f.cw = (led_f.cw * (1.0 - FILT_COEF)) + (in.cw * FILT_COEF);
  return led_f;
}


rgbywwcw calculateColorTemp(rgbywwcw in) {
  rgbywwcw out = in;
  float temp = (in.b - in.y);
  out.ww = min(uint8_t(min(int(out.ww + temp), 255)), out.ww);
  out.cw = min(uint8_t(min(int(out.cw - temp), 255)), out.cw);
  return out;
}

rgbywwcw rgb_to_rgbywwcw_struct(uint8_t r, uint8_t g, uint8_t b) {
  rgbywwcw out = {r, g, b, 0, 0, 0};
  return out;
}

rgbywwcw rgb_to_rgbw(rgbywwcw in) {
  rgbywwcw out;
  //Get the maximum between R, G, and B
  double tM = max(in.r, max(in.g, in.b));
  uint32_t ret = 0;

  //If the maximum value is 0, immediately return pure black.
  if (tM == 0) {
    out = {0, 0, 0, 0, 0, 0};
    return out;
  }

  //This section serves to figure out what the color with 100% hue is
  double multiplier = 255.0f / tM;
  double hR = in.r * multiplier;
  double hG = in.g * multiplier;
  double hB = in.b * multiplier;

  //This calculates the Whiteness (not strictly speaking Luminance) of the color
  double M = max(hR, max(hG, hB));
  double m = min(hR, min(hG, hB));
  double Luminance = ((M + m) / 2.0f - 127.5f) * (255.0f / 127.5f) / multiplier;

  //Calculate the output values
  int Wo = uint32_t(Luminance);
  int Bo = uint32_t(in.b - Luminance);
  int Ro = uint32_t(in.r - Luminance);
  int Go = uint32_t(in.g - Luminance);

  //Trim them so that they are all between 0 and 255
  if (Wo < 0) Wo = 0;
  if (Bo < 0) Bo = 0;
  if (Ro < 0) Ro = 0;
  if (Go < 0) Go = 0;
  if (Wo > 255) Wo = 255;
  if (Bo > 255) Bo = 255;
  if (Ro > 255) Ro = 255;
  if (Go > 255) Go = 255;

  out.r = Ro;
  out.g = Go;
  out.b = Bo;
  out.y = in.y;
  out.ww = Wo;
  out.cw = Wo / 2;

  return out;
}

hsv rgb2hsv(double r, double g, double b) {
  hsv         out;
  double      min, max, delta;

  min = r < g ? r : g;
  min = min  < b ? min  : b;

  max = r > g ? r : g;
  max = max  > b ? max  : b;

  out.v = max;                                // v
  delta = max - min;
  if (delta < 0.00001)
  {
    out.s = 0;
    out.h = 0; // undefined, maybe nan?
    return out;
  }
  if ( max > 0.0 ) { // NOTE: if Max is == 0, this divide would cause a crash
    out.s = (delta / max);                  // s
  } else {
    // if max is 0, then r = g = b = 0
    // s = 0, h is undefined
    out.s = 0.0;
    out.h = NAN;                            // its now undefined
    return out;
  }
  if ( r >= max )                          // > is bogus, just keeps compilor happy
    out.h = ( g - b ) / delta;        // between yellow & magenta
  else if ( g >= max )
    out.h = 2.0 + ( b - r ) / delta;  // between cyan & yellow
  else
    out.h = 4.0 + ( r - g ) / delta;  // between magenta & cyan

  out.h *= 60.0;                              // degrees

  if ( out.h < 0.0 )
    out.h += 360.0;

  return out;
}

rgbywwcw hsv_to_rgby_naive(hsv hsv) {
  rgbywwcw _tmpmdl;
  memset(&_tmpmdl, 0, sizeof(_tmpmdl));
  return hsv_to_rgby_naive(hsv.h / 360.0, hsv.s, hsv.v, _tmpmdl);
}

rgbywwcw hsv_to_rgby_naive(double h, double s, double v) {
  rgbywwcw _tmpmdl;
  memset(&_tmpmdl, 0, sizeof(_tmpmdl));
  return hsv_to_rgby_naive(h, s, v, _tmpmdl);
}


rgbywwcw hsv_to_rgby_naive(double h, double s, double v, rgbywwcw colorModel) {
  if (s == 0.0) {
    v = v * 255;

    colorModel =  (struct rgbywwcw) {
      v, v, v, v, colorModel.ww, colorModel.cw
    };
  }

  int i = int(h * 8.0);

  double f = (h * 8.0) - i;
  double b = v * (1.0 - s);
  double d = v * (1.0 - s * f);
  double u = v * (1.0 - s * (1.0 - f));
  i = i % 8;

  d = d * 255;
  b = b * 255;
  v = v * 255;
  u = u * 255;

  if (i == 0)colorModel =  (struct rgbywwcw) {
    v, b, b, u, colorModel.ww, colorModel.cw
  };

  if (i == 1)colorModel =  (struct rgbywwcw) {
    d, b, b, v, colorModel.ww, colorModel.cw
  };

  if (i == 2)colorModel =  (struct rgbywwcw) {
    b, u, b, v, colorModel.ww, colorModel.cw
  };

  if (i == 3)colorModel =  (struct rgbywwcw) {
    b, v, b, d, colorModel.ww, colorModel.cw
  };

  if (i == 4)colorModel =  (struct rgbywwcw) {
    b, v, u, b, colorModel.ww, colorModel.cw
  };

  if (i == 5)colorModel =  (struct rgbywwcw) {
    b, d, v, b, colorModel.ww, colorModel.cw
  };

  if (i == 6)colorModel =  (struct rgbywwcw) {
    u, b, v, b, colorModel.ww, colorModel.cw
  };

  if (i == 7)colorModel =  (struct rgbywwcw) {
    v, b, d, b, colorModel.ww, colorModel.cw
  };
  return colorModel;
}

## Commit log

2021-12-29 added hex-led-board
    [hex_led_board-B_Cu.gbl, hex_led_board-B_Mask.gbs, hex_led_board-B_Paste.gbp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]
2021-12-29 added hex base, missing silkscreen
    [hex_base.kicad_pcb, hex_base.sch]
2021-12-29 added hex-top
    [hex_top.kicad_pcb, hex_top.sch, hex_top.step]
2021-12-29 added wall-1
    [wall.kicad_pcb, wall.sch]
2021-12-29 added openscad mockup
    [lamp.scad, lamp_wall_1.dxf]
2021-12-29 finished wall
    [wall.kicad_pcb, wall.sch]
2021-12-29 finished led board
    [hex_led_board.kicad_pcb, hex_led_board.sch, hex_led_board.step]
2021-12-29 finished wall board
    [wall.kicad_pcb]
2021-12-29 removed gerber folder
    [hex_led_board-B_Cu.gbl, hex_led_board-B_Mask.gbs, hex_led_board-B_Paste.gbp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]
2021-12-29 finished top
    [hex_top.kicad_pcb, hex_top.step]
2021-12-29 fitted led board onto base, todo: buttons, fix light sensor, more caps?, silkscreen
    [hex_base.kicad_pcb, hex_base.sch]
2021-12-29 added USB wall
    [wall_usb-B_Cu.gbl, wall_usb-B_Mask.gbs, wall_usb-B_Paste.gbp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]
2021-12-29 finished wall, exported gerber
    [wall-B_Cu.gbl, wall-B_Mask.gbs, wall-B_Paste.gbp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]
2021-12-29 exported top gerber
    [hex_top-B_Cu.gbl, hex_top-B_Mask.gbs, hex_top-B_Paste.gbp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]
2021-12-29 exported led board gerber
    [hex_led_board-B_Cu.gbl, hex_led_board-B_Mask.gbs, hex_led_board-B_Paste.gbp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]
2021-12-29 finished base, exported gerber
    [hex_base-B_Cu.gbl, hex_base-B_Mask.gbs, hex_base-B_Paste.gbp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]
2022-04-28 updated files
    [hex_base.kicad_pcb, hex_base.kicad_sch, hex_base.sch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]
2022-04-29 updated file
    [hex_base-B_Cu.gbl, hex_base-B_Mask.gbs, hex_base-B_Paste.gbp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]
2023-03-02 added 3D files
    [laemp_panel.scad]
2023-03-02 renamed base files
    [hex_base-B_Cu.gbl, hex_base-B_Mask.gbs, hex_base-B_Paste.gbp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]
2023-03-02 renamed led board
    [hex_led_board-B_Cu.gbl, hex_led_board-B_Mask.gbs, hex_led_board-B_Paste.gbp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]
